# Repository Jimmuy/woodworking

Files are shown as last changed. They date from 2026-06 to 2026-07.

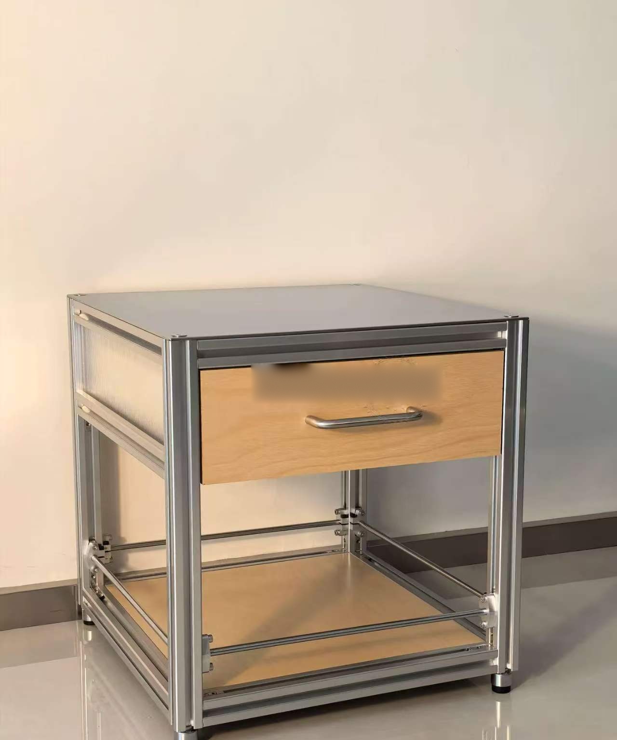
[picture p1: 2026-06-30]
nightstand/Nightstand3.jpg

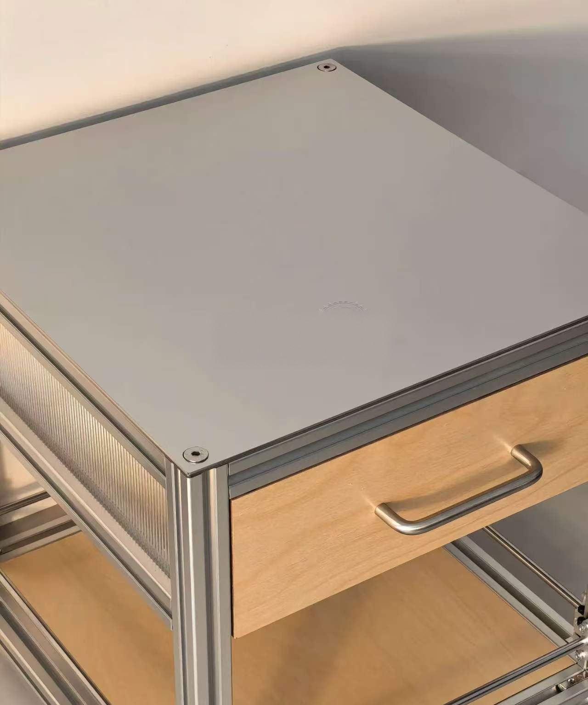
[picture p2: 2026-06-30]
nightstand/Nightstand2.jpg

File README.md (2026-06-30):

# Woodworking

Personal woodworking and small fabrication project archive.

This repository is used to keep project reference photos, design notes, CAD/OpenSCAD models, fabrication checklists, exported review files, and assembly planning documents.

## Projects

### `nightstand/`

Aluminum-profile nightstand / bedside cabinet project.

Contents:

- `床头柜建模.scad` - OpenSCAD parametric machining and assembly model.
- `床头柜加工清单.md` - fabrication dimensions, hardware BOM, original-list comparison, and assembly feasibility review.
- `Nightstand1.jpg` - `Nightstand5.jpg` - redacted reference photos used for visual and construction details.
- `exports/maycad/` - Windows / MayCAD review exports and notes.
- `exports/maycad/bed_desk_assembly_closed_350.3mf` - preferred complete assembly review file.
- `exports/maycad/bed_desk_assembly_closed_350.stl` - complete assembly STL backup.
- `exports/maycad/bed_desk_drawer_closed_350.stl` - drawer fully-closed state check.
- `exports/maycad/bed_desk_drawer_open_350.stl` - drawer fully-open state check.
- `exports/maycad/bed_desk_top_plate_3mm.stl` - top metal plate check.
- `exports/maycad/README.md` - export-file usage notes.

Current nightstand design baseline:

- Overall size: 400 x 400 x 420 mm.
- Frame: 2020 aluminum extrusion.
- Top plate: 400 x 400 x 3 mm, M5 countersunk holes.
- Drawer slides: 350 mm detachable-inner-rail three-section slides.
- Drawer box: 326 mm wide x 350 mm deep x 112 mm high.

## Conventions

- Keep one project per top-level folder.
- Put reusable models, cut lists, reference photos, and export files under that project folder.
- Redact personal IDs, account names, or watermarks from reference photos before committing.
- Treat generated exports as review/check files; fabrication dimensions should be verified against the source model and project BOM.

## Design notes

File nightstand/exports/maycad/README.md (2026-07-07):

# Windows / MayCAD 检查文件说明

## 优先打开

- `bed_desk_assembly_closed_350.3mf`：完整床头柜，默认抽屉完全关闭。
- `bed_desk_assembly_closed_350.stl`：完整床头柜 STL 备份。
- `bed_desk_assembly_open_350.3mf`：完整床头柜，抽屉按350mm额定行程完全打开。
- `bed_desk_assembly_open_350.stl`：抽屉完全打开总装 STL 备份。
- `bed_desk_exploded_350.3mf`：整柜主要零件和抽屉五面板爆炸图。
- `bed_desk_exploded_350.stl`：爆炸图 STL 备份。
- `bed_desk_exploded_350.scad`：爆炸图独立 OpenSCAD 源文件，直接打开即可看到爆炸图。

## 抽屉检查

- `bed_desk_drawer_closed_350.stl`：抽屉完全关闭检查。
- `bed_desk_drawer_open_350.stl`：抽屉按 350mm 全拉出滑轨完全打开检查，只包含框架、固定轨和抽屉运动件。

## 顶板检查

- `bed_desk_top_plate_3mm.stl`：3mm 顶部金属板、M5 沉头孔、R1.5 外角和 C0.35 轻微破边。

## 当前关键尺寸

- 外形：400 x 400 x 420mm。
- 顶板：400 x 400 x 3mm。
- 2020 立柱：387mm x 4。
- 2020 横梁：360mm x 12。
- 抽屉滑轨：350mm 可拆内轨三节滑轨。
- 抽屉盒：332mm 宽 x 350mm 深 x 112mm 高。
- 抽屉盒结构：左右侧板 + 内前板 + 背板 + 底板，装饰前脸最后可调固定。
- 上层长虹板/亚克力：左右侧板 368 x 148 x 4mm，后侧板 352 x 148 x 4mm，按入槽尺寸和滑轨避让尺寸下料。
- 滑轨隐藏承载条：400 x 30 x 3mm x2；固定轨锁在承载条上，承载条前后端锁入2020立柱槽。
- 抽屉完全关闭：前脸外表面与前侧铝型材外表面平齐。
- 抽屉关闭后后方余量：约 12mm。
- 抽屉底板：320 x 338 x 6mm，四边进入6mm槽，槽底距抽屉侧板下边8mm。
- 抽屉底部结构余量：约 14mm。

## 注意

这些导出文件用于 Windows 端检查空间、外观和装配干涉。正式下料仍以 `../../床头柜加工清单.md` 和 `../../床头柜建模.scad` 为准。

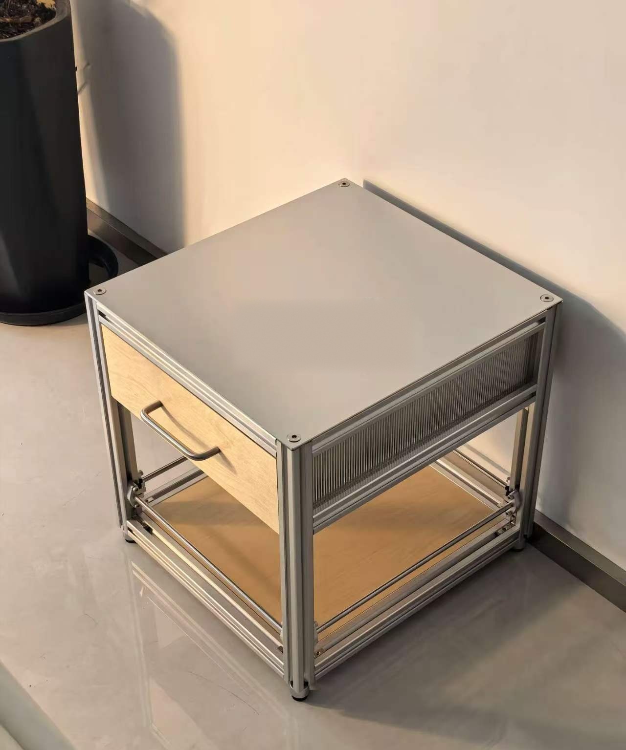
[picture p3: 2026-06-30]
nightstand/Nightstand1.jpg

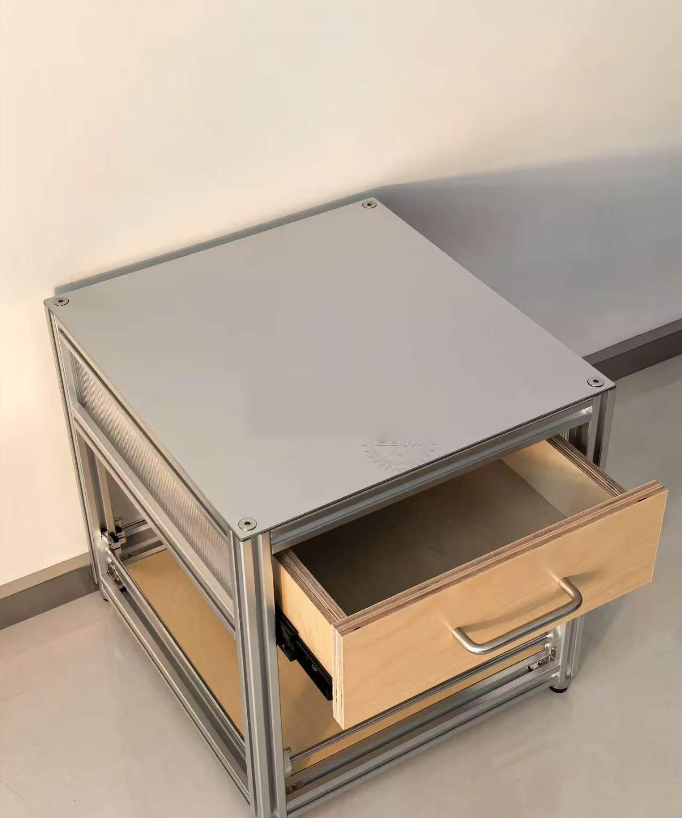
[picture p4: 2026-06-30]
nightstand/Nightstand4.jpg

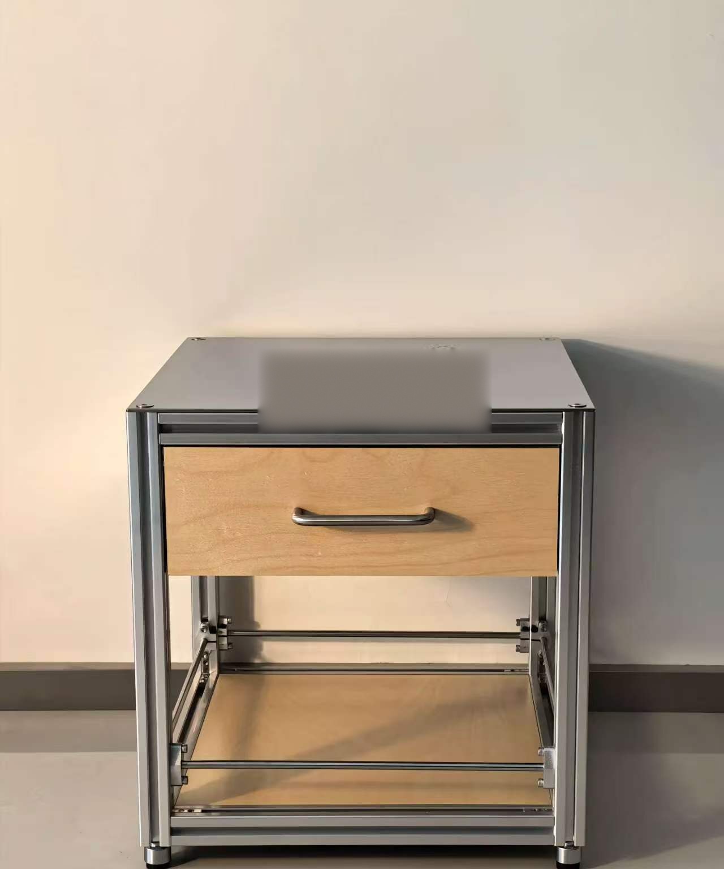
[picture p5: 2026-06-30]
nightstand/Nightstand5.jpg

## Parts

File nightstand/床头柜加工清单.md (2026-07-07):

# 2020铝型材床头柜加工与采购清单

## 设计基准

- 外形尺寸：400mm 宽 × 400mm 深 × 420mm 高。
- 主框架：2020 铝型材，三层框架，四根立柱。
- 上层：木抽屉 + 左右/后侧 4mm 长虹玻璃或亚克力；左右侧板走外侧型材槽位，板边由槽/U型胶条/压片遮住，只露出长虹纹理面。抽屉滑轨不固定在亚克力上，需固定在隐藏金属承载条上。
- 下层：18mm 置物板嵌入底层 2020 内框，板面与铝型材上表面齐平；外侧四面 8mm 不锈钢光轴护栏。
- 模型文件：`床头柜建模.scad`，已补入加工尺寸、孔位、滑轨、抽屉板件和主要五金位置。
- 单独导出零件时可修改 `render_target`，支持 `assembly`、`assembly_open`、`exploded`、`frame`、`top_plate`、`glass_panels`、`shelf`、`guard_rails`、`drawer`、`fixed_slides`、`drawer_install`、`drawer_closed`、`drawer_open`、`feet`。
- 独立爆炸图源文件：`bed_desk_exploded_350.scad`，默认打开即为整柜主要零件和抽屉五面板爆炸图。
- 型材接口按隐藏盲连/内置连接件处理，外侧不要布置外露黑色螺丝。

## 型材下料与加工

| 项目 | 规格 | 数量 | 加工要求 |
| --- | --- | ---: | --- |
| 2020铝型材立柱 | 387mm | 4根 | 顶端按顶部沉头螺丝攻 M5 或采用卖家配套端面连接件；底部调节脚若用M6，需确认型材中心孔可攻M6或加转换脚座。 |
| 2020铝型材横梁 | 360mm | 12根 | 三层框架，每层4根；使用隐藏盲连/内置连接件，外侧不要外露螺丝头。 |
| 型材总长 | 5868mm | 约5.9m | 考虑锯缝和备料，建议采购 6.2m 到 6.5m。 |
| 盲连打孔/攻牙 | M6 或按卖家系统 | 1套 | 需要让型材卖家确认“2020盲连/直连”加工方案，避免只买螺丝但无法锁紧。 |

## 板材和面材下料

| 项目 | 尺寸 | 数量 | 说明 |
| --- | --- | ---: | --- |
| 顶部金属板 | 400 × 400 × 3mm | 1块 | 304不锈钢或铝板；四角预留 M5 沉头孔，孔中心距外边约10mm，对应四根立柱中心；沉头直径约10.5mm、深约2.5mm，螺丝装后与板面平齐；外角建议 R1.5-R2，四周只做 C0.3-C0.5 轻微破边。 |
| 底层置物板 | 356 × 356 × 18mm | 1块 | 嵌入底层2020内框，顶面与底层横梁上表面齐平；下方由槽内托片承重，不要只靠压片夹住。 |
| 左右侧长虹板/亚克力 | 368 × 148 × 4mm | 2块 | 上层抽屉区侧面，按 360×140 开口、单边约5mm入槽和单边约1mm余量计算；嵌入型材槽/U型胶条后正面基本看不到板边。 |
| 后侧长虹板/亚克力 | 352 × 148 × 4mm | 1块 | 后侧板不穿到左右滑轨承载条区域；由上下槽/U型胶条和侧向限位片固定，避免与后端滑轨承载条干涉。 |
| 抽屉前脸 | 356 × 134 × 18mm | 1块 | 拉手孔距按96mm建模；实际按所购拉手复核。 |
| 抽屉侧板 | 350 × 112 × 12mm | 2块 | 12mm夹板或多层板；深度匹配350mm全拉出滑轨。 |
| 抽屉内前板 | 308 × 112 × 12mm | 1块 | 抽屉盒结构前板；预留长圆孔/过孔，装饰前脸最后从内侧微调后锁紧。 |
| 抽屉背板 | 308 × 112 × 12mm | 1块 | 适配332mm外宽抽屉盒。 |
| 抽屉底板 | 320 × 338 × 6mm | 1块 | 四边进入抽屉侧板/内前板/背板的6mm槽内；槽宽建议6.2mm，槽深6mm，槽底距板件下边8mm。 |
| 滑轨隐藏承载条 | 400 × 30 × 3mm | 2根 | 左右各一根，一体式金属扁条；承载条移到侧面型材槽位内侧，不与抽屉前脸、后侧板、侧面长虹板干涉。两端各2个M5过孔，中段攻M4孔固定滑轨。 |

## 完整五金采购清单

| 类别 | 规格/建议 | 数量 | 用途 |
| --- | --- | ---: | --- |
| 不锈钢光轴/圆管 | 直径8mm，长360mm | 4根 | 下层四面护栏。 |
| 2020槽内式圆杆夹/通用光轴连接件 | 8mm圆杆用，M5/T型滑块固定，抱箍中心相对槽中心需有约14mm偏置 | 8个 | 每根光轴两端固定；优先选能嵌入2020型材槽、带偏置抱箍的通用圆杆夹，不建议用外置SK8座。 |
| 抽屉滑轨 | 350mm三节静音阻尼滑轨，低位侧装/底边侧装，必须可拆内轨/带释放扣 | 1双 | 左右各一根；外固定轨锁在隐藏承载条上，活动内轨先锁到抽屉木盒底边侧面，再从正面推入合轨；不接触亚克力。 |
| 极简一字拉手 | 建议孔距96mm | 1个 | 抽屉前脸。 |
| 型材隐藏连接件/盲连螺丝 | 2020用隐藏盲连件，或按卖家系统 | 24套 | 12根横梁两端连接；外侧不露黑色螺丝头。 |
| 顶板银色沉头螺丝 | M5×8-10 不锈钢沉头内六角/梅花 | 4个 | 固定顶部金属板，装入预留沉头孔后与板面基本齐平。 |
| 槽内滑块螺母 | 2020-M5标准滑块 | 建议50个 | 圆杆夹、滑轨、底板托片、玻璃压条/限位片等；若圆杆夹自带滑块可相应减少。 |
| M5短螺丝 | M5×8 / M5×10 / M5×12 混合，承载条位置优先低头/薄头 | 建议60个 | 搭配槽内滑块，固定各类附件和滑轨承载条；滑轨背后不要使用过厚螺丝头。 |
| 底部调节脚 | M6调节脚，脚杯直径约25-30mm | 4个 | 四根立柱底部找平。 |
| 底板槽内承托片 | 2020槽用L型/托板式，托面约30-40mm | 至少4个，建议6-8个 | 嵌入底层型材槽，从下方承接木板重量，四角/四边布置。 |
| 底板防上浮压片/卡条 | 2020槽用，适配18mm板或按实际板厚 | 4个左右 | 负责限位和防止木板上浮，不作为主要承重件。 |
| 玻璃/亚克力U型胶条 | 4mm板用，建议3.5-4m | 1套 | 三块上层面板四周理论总长约3.06m，考虑切损和转角余量不建议只买3m。 |
| 玻璃压条/限位片 | 2020槽用小压片 | 12个左右 | 每块板四边限位，防止晃动。 |
| 承载条到型材固定件 | M5×8/10低头螺丝 + 2020 T型滑块 | 8套 | 每根承载条前后各2套；过孔直径5.5mm，锁入前后立柱内侧槽。 |
| 滑轨到承载条螺丝 | M4×8低头/盘头螺丝 | 8个，建议买12个 | 每侧固定轨4个；承载条攻M4牙，底孔直径3.3mm。若只用3mm铝条，建议改4-5mm条或加M4拉铆螺母。 |
| 滑轨到抽屉木盒螺丝 | M4×10或滑轨自带木螺丝 | 8个，建议买12个 | 每侧活动内轨4个；锁在抽屉侧板外侧低位，木板预钻2.0-2.5mm导孔。 |
| 抽屉盒连接木螺丝 | M3.5×25或M4×25，需预钻孔 | 8个，建议买12个 | 左右侧板从外侧锁内前板/背板，每个角2个，配木工胶。 |
| 抽屉底板入槽固定 | 木工胶 + 6.2mm槽 | 1套 | 底板四边入槽承托，不建议把6mm底板作为主要吃螺丝件；需要防松可在背板下沿加2颗M3×10限位螺丝。 |
| 抽屉前脸可调固定件 | M4×16/20 + 大垫片，或抽屉前脸调节连接件 | 4套 | 前脸最后安装，用长孔/大垫片微调上下左右缝，保证关闭后与铝型材平齐。 |
| 拉手配套螺丝 | M4，长度适配18mm前脸 | 2个 | 拉手通常自带，但要确认螺丝长度能锁紧。 |
| 木工胶 | 白乳胶/木工胶 | 1支 | 抽屉盒板件连接补强。 |
| 防松件 | 螺纹胶/弹垫/平垫 | 1套 | 振动位置建议使用。 |

## 与原清单对比

| 原清单项目 | 原数量 | 结论 | 还需要补充/修正 |
| --- | ---: | --- | --- |
| 不锈钢光轴/圆管 8mm×360mm | 4根 | 足够 | 无。 |
| 光轴卡槽固定座 | 8个 | 数量够，规格需调整 | 建议改为 2020槽内式8mm圆杆夹/通用光轴连接件，能配合T型滑块嵌入型材槽；不要选外置SK8座。 |
| 抽屉滑轨 300mm | 1双 | 不建议继续用300mm | 400mm深柜体净安装深度约360mm，300mm滑轨能装，但完全关闭后抽屉后方会留下约60mm空隙，储物深度偏浪费。建议改350mm可拆内轨三节滑轨。 |
| 极简一字拉手 | 1个 | 足够 | 需确认孔距；模型按96mm孔距。 |
| 型材连接螺丝 M6/M5×25 | 24个 | 方案需调整 | 参考图接口处不应外露螺丝；建议改为隐藏盲连/内置连接件，数量按12根横梁两端共24套。 |
| 槽内滑块螺母 | 约30个 | 偏少 | 建议增至50个，并配 M5×8/10/12 螺丝约50个。 |
| 底部调节脚 | 4个 | 足够 | 可用M6调节脚，但必须让型材卖家确认底端中心孔可攻M6；若型材统一只能攻M5，则改用M5调节脚或转换脚座。 |

## 原清单缺少的关键项目

| 缺少项目 | 建议数量 | 为什么需要 |
| --- | ---: | --- |
| 2020铝型材立柱 387mm | 4根 | 主框架竖向支撑；长度已按3mm顶板重新计算。 |
| 2020铝型材横梁 360mm | 12根 | 上/中/下三层框架。 |
| 顶部金属板 | 1块 | 形成床头柜台面。 |
| 顶板沉头孔加工和银色沉头螺丝 | 4套 | 固定顶板到四根立柱；螺丝装后应与不锈钢板面基本齐平。 |
| 顶板外轮廓倒角/圆角加工 | 1项 | 顶板外角按2020铝型材外角做 R1.5-R2；四周只做 C0.3-C0.5 轻微破边，不要做过大倒角，否则会露出下方型材角。 |
| 底层置物板 | 1块 | 下层储物面。 |
| 长虹玻璃/亚克力板 | 3块 | 左右/后侧上层围挡；板边需要被型材槽、U型胶条或压片遮住。 |
| 4mm U型胶条和玻璃压片 | 1套 | 固定并防震，不然板件会晃。 |
| 抽屉木板拆料 | 1套 | 原清单只有滑轨和拉手，没有抽屉本体。 |
| 抽屉内前板 | 1块 | 大前脸不能直接作为抽屉盒结构件；需要内前板承受盒体连接，并给装饰前脸预留微调空间。 |
| 抽屉盒连接木螺丝/底板入槽加工 | 1套 | 抽屉盒四角用8颗结构螺丝+木工胶；底板靠四边槽承托，槽宽/槽深必须加工准确。 |
| 抽屉前脸可调固定件 | 4套 | 最后调节抽屉前脸，使完全关闭时与前侧铝型材外表面平齐。 |
| 拉手配套螺丝 | 2个 | 需按18mm前脸确认长度。 |
| 滑轨隐藏承载条 | 400×30×3mm 2根 | 解决滑轨不能打在亚克力上的问题；承载条移到侧面型材槽位内侧，同时避开抽屉前脸、后侧板和侧面长虹板。 |
| 底板槽内承托片 | 至少4个，建议6-8个 | 让底板扣入底层型材内框后有可靠承重支撑，并与型材上表面齐平。 |
| 底板防上浮压片/卡条 | 4个左右 | 防止木板搬动时上浮或滑动，不能替代底部托片承重。 |
| M5短螺丝套装 | 约60个 | 原清单只有滑块螺母，没有足够配套螺丝；新增滑轨承载条后建议增加余量。 |
| 型材加工服务 | 1套 | 包含切割、端面攻牙、盲连孔位，决定能否顺利装配。 |

## 加工前复核点

1. 顶板孔中心按模型是距外边约10mm，适配2020立柱中心孔；下单前让金属板加工方和型材方同时确认。当前模型按 M5 沉头孔：通孔约5.5mm，沉头直径约10.5mm，沉头深约2.5mm，建议使用3mm金属板。
2. 顶板沉头螺丝建议用银色不锈钢件，拧紧后与不锈钢面板基本齐平；如果改 M6，必须同步改通孔、沉头直径、顶板厚度和立柱攻牙规格。型材顶端攻牙规格、底部调节脚螺纹规格必须由同一家型材卖家确认，不能默认M5/M6通用。
3. 顶板外轮廓不要按大 R4 或大倒角处理；建议按实际2020铝型材外角做 R1.5-R2，四周只做 C0.3-C0.5 轻微破边。这样顶板外轮廓能覆盖立柱外角，不会从上方看到下方铝型材角。
4. 如果卖家不支持2020隐藏盲连/内置连接件，改用角码会破坏参考图这种无外露螺丝效果，螺丝和滑块数量也要重新计算。
5. 长虹玻璃/亚克力不能按开口净尺寸下料。左右侧板按 368×148×4mm，后侧板按 352×148×4mm；后侧板主动避开滑轨承载条端部，不再强行做满宽。若采购的2020型材槽深、U型胶条厚度不同，必须按实物重新复核后再下单。
6. 抽屉滑轨实际高度、厚度、孔位差异较大；当前模型按350mm全拉出滑轨计算，关闭时抽屉前脸外表面与前侧铝型材外表面平齐，抽屉后方保留约12mm安全间隙。买到具体滑轨后，应把 `slide_h`、`slide_thk`、`slide_len` 回填到 `床头柜建模.scad`，并保持低位贴近抽屉盒底边。滑轨必须可拆内轨，否则侧板装好后很难完成装配和维护。
7. 滑轨不要安装在亚克力/长虹板上。推荐装配顺序是：先半锁2020框架并预放T型滑块；固定左右隐藏承载条并试装滑轨；确认抽屉合轨顺畅后，把长虹板/亚克力带U型胶条滑入槽内，再最终锁紧框架和压片；抽屉盒在柜体外组装并锁活动内轨，最后从正面推入合轨并调缝。
8. 滑轨隐藏承载条推荐使用一体式 400×30×3mm 金属扁条 ×2。前一次问题来自承载条位置偏内，会和抽屉前脸/侧板区域抢空间；当前模型已把承载条移到侧面型材槽位内侧，静态上与抽屉前脸、后侧板、侧面长虹板均有间隙。
9. 当前模型按 12mm滑轨 + 每侧2mm装配/调节余量计算，抽屉盒外宽为332mm。若实际滑轨厚度变化，抽屉盒外宽应按 `360 - 2 × (滑轨厚度 + 每侧装配余量)` 重新计算；每侧装配余量不建议小于1.5mm。承载条位于侧面型材内侧槽位，不再占用抽屉盒净宽。
10. 如果坚持使用原清单的300mm滑轨，抽屉盒深度应改回300mm，完全关闭后抽屉后方会留约60mm空隙；这不是装不上的问题，而是储物深度利用不足。
11. 抽屉前脸不要和抽屉盒一次性死锁；抽屉盒应包含12mm内前板，装饰前脸用4点可调固定件或长孔+大垫片锁在内前板上，整柜试装后再调平、调缝、锁紧。
12. 长虹玻璃建议倒角或磨边；亚克力更好加工，但耐刮性弱于玻璃。侧面板不要外凸安装，板边应藏进型材框或U型胶条。
13. 底层置物板不要放在型材上方；应下沉嵌入底层2020内框，顶面和底层横梁上表面齐平。底板下方至少四处使用槽内式承托片承重，压片/卡条只负责防上浮和定位。
14. 如果底板承重要放书、设备或较重物品，建议把底板槽内承托片从4个增加到6-8个，前后边各2-3个，左右边按需要补强。
15. 光轴固定件建议采购“2020槽内式8mm圆杆夹/通用光轴连接件”，通常由圆杆夹体 + M5螺丝 + T型滑块组成，能直接嵌入型材槽；抱箍中心相对槽中心需要约14mm偏置，否则圆杆位置会顶住立柱或出现悬空。
16. 抽屉底板采用四边入槽，底板尺寸为320×338×6mm；左右侧板、内前板、背板都需开6.2mm宽、6mm深的底板槽，槽底距板件下边8mm。不开槽会导致底板固定方式和当前模型不一致。
17. 所有板件建议保留0.5-1mm加工误差余量，先试装框架，再锁紧面板和抽屉。

## 抽屉与滑轨下单复核

| 项目 | 当前确认值 | 加工/装配要求 |
| --- | --- | --- |
| 滑轨规格 | 350mm三节全拉出，低位侧装/底边侧装，可拆内轨 | 关闭时抽屉前脸外表面与前侧铝型材外表面齐平；全开按350mm额定行程校核。必须能拆内轨，否则侧板装好后不可维护。 |
| 固定轨安装位置 | 左右隐藏承载条内侧，中心约在抽屉底边上方19.5mm | 滑轨不碰亚克力；承载条先锁到型材，再从抽屉口方向上固定轨。 |
| 活动内轨安装位置 | 抽屉左右侧板外侧低位，滑轨底边距抽屉侧板下边约2mm | 在柜体外先把活动内轨锁到抽屉盒，再从正面推入合轨。 |
| 承载条固定 | 每根承载条前后各2个M5过孔 | 孔径5.5mm，配M5×8/10低头螺丝+2020 T型滑块，共8套。 |
| 固定轨到承载条 | 每侧4颗M4×8，共8颗 | 承载条攻M4，底孔3.3mm；孔位按实际滑轨长圆孔复核，模型示意为y向约 -120、-45、45、120mm。 |
| 活动内轨到抽屉侧板 | 每侧4颗M4×10或滑轨配套木螺丝，共8颗 | 木板预钻2.0-2.5mm导孔，螺丝不要穿透12mm侧板内表面。 |
| 抽屉盒五面板 | 侧板350×112×12mm×2；内前板308×112×12mm×1；背板308×112×12mm×1；底板320×338×6mm×1 | 抽屉盒外宽332mm、深350mm、高112mm；底板四边入槽6mm。 |
| 抽屉盒结构螺丝 | M3.5×25或M4×25，共8颗 | 四个角每角2颗，从左右侧板外侧锁入内前板/背板，配木工胶。 |
| 装饰前脸固定 | M4×16/20 + 大垫片，共4套 | 内前板做长孔/过孔，最后调缝后锁紧；拉手另外2颗M4按拉手配套长度。 |

## 爆炸图对照复核

爆炸图中的主要可加工/采购单元与清单一致：4根立柱、12根横梁、1块顶板、3块长虹板/亚克力、1块底层置物板、4处底板托片、4根光轴、8个光轴连接件、2根滑轨承载条、1副滑轨、抽屉五面板、1块装饰前脸和1个拉手。隐藏盲连件、T型滑块、玻璃压片、胶条、木工胶和防松件属于小五金/耗材，爆炸图不逐个拆开显示，但清单已按装配需要列入。

## 开孔与孔位复核

下表坐标以零件自身为基准，除特别说明外，孔位从零件中心线对称计算；正式打孔前仍需把实际购买滑轨、拉手、圆杆夹和型材槽宽实物复核一遍。

| 零件/孔位 | 孔径/孔型 | 数量 | 孔中心位置 |
| --- | --- | ---: | --- |
| 顶部金属板固定孔 | M5通孔 Ø5.5；90度沉头 Ø10.5，深约2.5mm | 4 | 板面坐标 X/Y = ±190mm，即距四边各10mm，对应4根2020立柱中心孔。 |
| 滑轨隐藏承载条到型材 | M5过孔 Ø5.5 | 8 | 每根400×30×3mm承载条4孔：长度方向距两端各10mm；高度方向距下边7mm和23mm。配M5×8/10低头螺丝+2020 T型滑块。 |
| 固定轨到滑轨承载条 | M4攻牙，底孔 Ø3.3；若不用攻牙则改 Ø4.5 过孔+铆螺母/背母 | 8 | 每根承载条4孔，模型参考为距前端约75、150、240、315mm，高度方向距下边15mm。实际以所购滑轨长圆孔为准，建议先装承载条和滑轨试位后再钻。 |
| 活动内轨到抽屉侧板 | 按滑轨配套木螺丝预钻 Ø2.0-2.5，或M4木螺丝导孔 | 8 | 每侧4孔；模型参考为距抽屉侧板前端约57、132、222、297mm，高度方向距侧板下边约19.5mm。实际以所购滑轨孔位为准。 |
| 抽屉前脸拉手孔 | M4通孔 Ø4.5 | 2 | 孔距96mm；在356×134mm前脸上，孔中心距左边约130mm和226mm，距上下边各67mm。 |
| 抽屉内前板到装饰前脸调节孔 | 竖向长孔 5×14mm，配M4×16/20和大垫片 | 4 | 在308×112mm内前板上，孔中心距左边约42mm和266mm；距下边约22mm和90mm。 |
| 抽屉盒侧板连接孔 | M3.5/M4木螺丝预钻；侧板通孔可按 Ø3.5-4.2，端面导孔按 Ø2.0-2.5 | 8 | 左右侧板从外侧锁内前板/背板；前后方向孔中心距侧板前/后端约6mm，高度方向距侧板下边18mm和94mm。 |
| 抽屉底板槽 | 6.2mm宽槽，槽深6mm | 4条槽 | 左右侧板、内前板、背板都开槽；槽底距板件下边8mm，适配320×338×6mm底板四边入槽。 |
| 底板托片/玻璃压片/光轴夹 | 通常用M5过孔 Ø5.5或购买件自带孔 | 按所购件 | 爆炸图只表达位置关系；这三类优先买2020槽内标准件，孔位按实物，不建议自行先打死孔。 |

## 本次静态与运动校核结果

本次按模型关键零件包围盒做了静态和抽屉0-350mm行程运动校核。滑轨固定轨/活动轨的套叠、抽屉底板四边入槽属于预期装配接触，不按干涉处理；其余最小单元未发现静态干涉和运动干涉。

| 校核项 | 结果 |
| --- | --- |
| 侧面长虹板到滑轨承载条 | X向净间隙约5mm。 |
| 侧面长虹板到固定滑轨 | X向净间隙约8.5mm。 |
| 抽屉前脸到滑轨承载条 | X向净间隙约2mm。 |
| 抽屉前脸到固定滑轨 | 关闭状态Y向净间隙约2mm。 |
| 后侧长虹板到滑轨承载条 | X向净间隙约4mm。 |
| 抽屉侧板到活动滑轨 | X向装配间隙约0.5mm，需按实际滑轨厚度复核。 |
| 抽屉完全关闭 | 前脸外表面Y=-200mm，与前侧铝型材外表面平齐；抽屉后方余量约12mm。 |
| 抽屉完全打开 | 抽屉盒背板相对固定滑轨/前框仍有约2mm间隙。活动轨与固定轨在额定350mm全开位置为滑轨内部止挡接触，属于标准全拉出状态；若购买超行程滑轨，需把实际行程回填模型再复核。 |
| 抽屉底部 | 抽屉盒底边到下方开口横梁约14mm，滑轨低位安装后仍可装配。 |

## 装配可行性复核

| 模块 | 可行性结论 | 关键检查 |
| --- | --- | --- |
| 铝型材框架 | 可装配 | 12根横梁使用隐藏盲连/内置连接件，外侧不露螺丝；下单时必须把盲连孔、端面攻牙和切割一起给型材卖家确认。 |
| 顶部金属板 | 可装配，需确认攻牙 | 3mm板可做M5沉头并保持平齐；四角孔位在立柱中心，顶端攻牙规格必须和M5沉头螺丝一致。 |
| 抽屉滑轨 | 可装配 | 选350mm可拆内轨三节滑轨；固定轨锁在400mm隐藏承载条上，承载条前后端锁入2020立柱槽；活动内轨在柜体外锁到抽屉盒，再从正面推入合轨。 |
| 抽屉盒 | 可装配 | 外宽332mm，深350mm，高112mm；增加12mm内前板，底板为320×338mm四边入槽；每侧保留2mm装配/调节余量；装饰前脸用4点可调固定件，最后调缝并锁紧。 |
| 侧面长虹板/亚克力 | 可装配 | 左右下料按368×148mm并走外侧槽位，后侧下料按352×148mm避开滑轨承载条端部；三块板均不承受滑轨载荷，不打滑轨孔。 |
| 底层置物板 | 可装配 | 底板嵌入底层内框，顶面与型材齐平；至少4个槽内承托片承重，压片/卡条只做防上浮和定位。 |
| 下层光轴护栏 | 可装配 | 采购2020槽内式8mm圆杆夹，配M5滑块，抱箍中心需相对槽中心有约14mm偏置；不要买外置SK8座，否则外观和装配空间都会偏离参考图。 |
| 调节脚 | 可装配，需确认螺纹 | M6脚垫稳定性较好，但需要底端攻M6或转换脚座；若型材卖家只能统一M5，则改M5脚垫。 |

## Windows/MayCAD 导出说明

- OpenSCAD 当前可直接导出 `STL`、`3MF`、`AMF`、`OFF`、`CSG` 等格式；本项目优先导出 `STL` 和 `3MF` 给 Windows 端确认。
- 本机没有 FreeCAD/CadQuery，因此不直接输出 STEP。若你的 Windows MayCAD 只支持 STEP/IGES，需要在 Windows 端用 FreeCAD、Fusion、SolidWorks 或 MayCAD 支持的转换工具从 STL/3MF 另转，或者提供 MayCAD 的明确导入格式后再重新导出。
- `STL` 是网格模型，适合确认空间、外观、干涉和装配关系；真正下料仍以本清单尺寸和 `床头柜建模.scad` 参数为准。

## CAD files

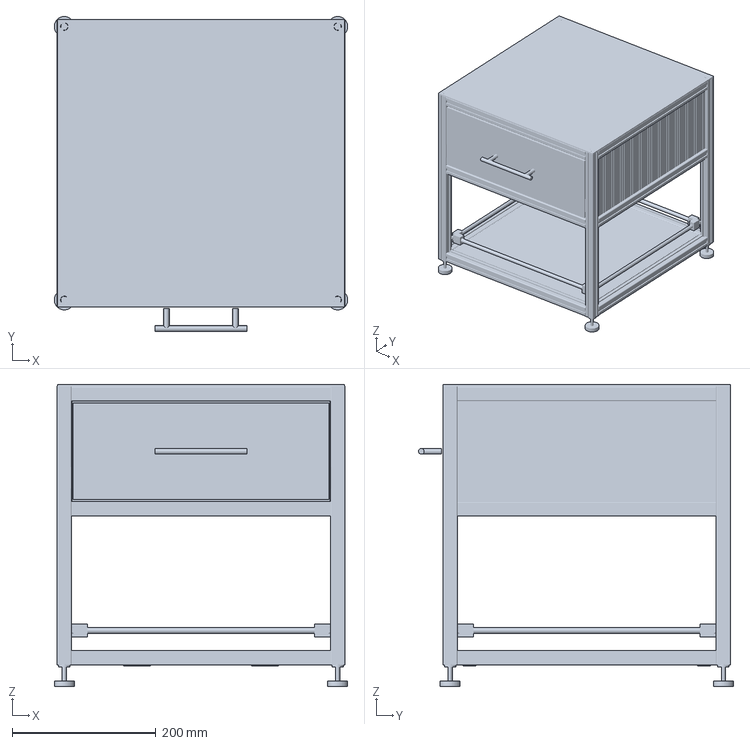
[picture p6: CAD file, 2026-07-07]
nightstand/exports/maycad/bed_desk_assembly_closed_350.3mf
408.0 x 438.0 x 420.0 mm

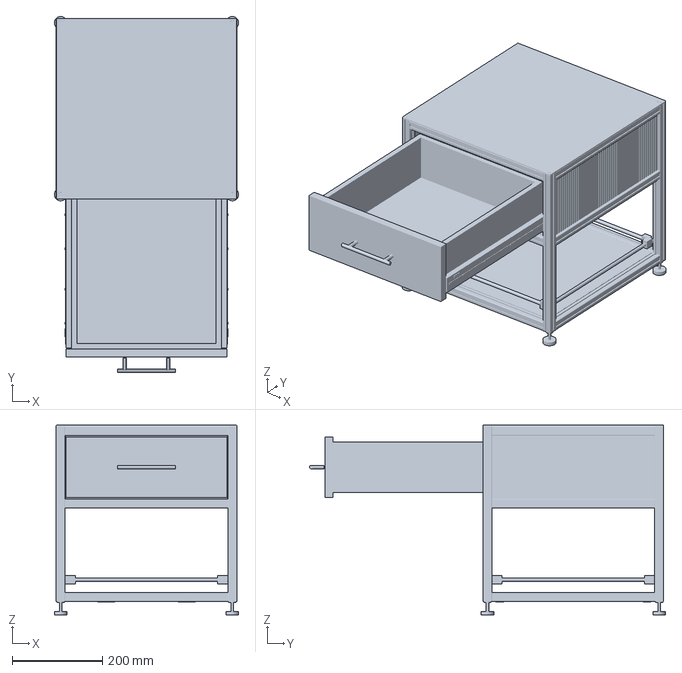
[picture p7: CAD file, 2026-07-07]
nightstand/bed_desk_assembly_open_350.3mf
408.0 x 788.0 x 420.0 mm

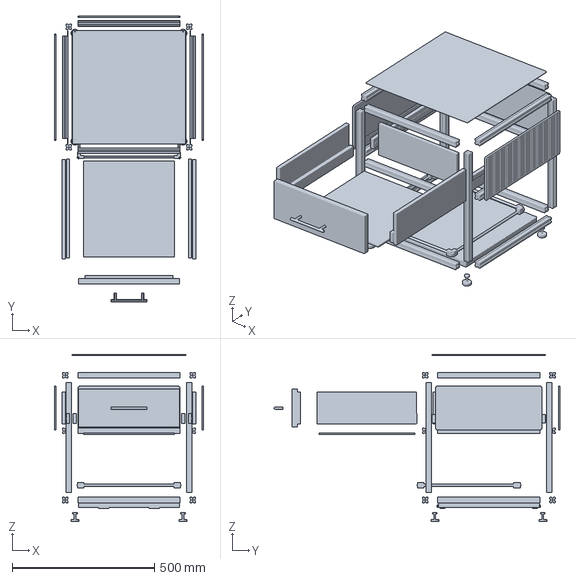
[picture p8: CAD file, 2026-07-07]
nightstand/bed_desk_exploded_350.3mf
525.7 x 1006.4 x 588.0 mm

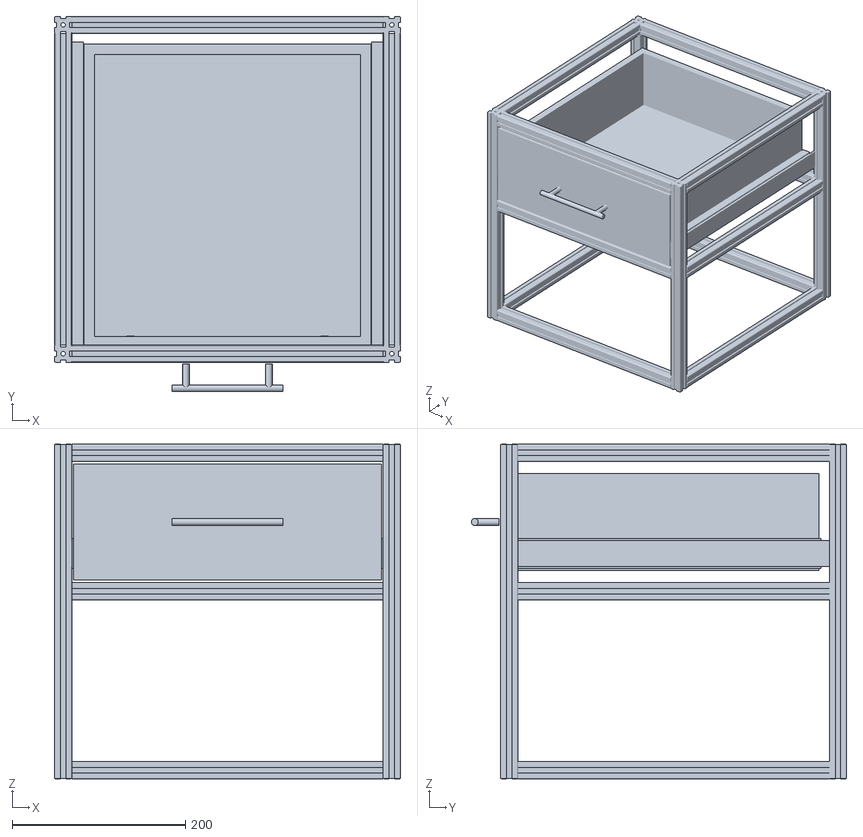
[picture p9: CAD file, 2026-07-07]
nightstand/exports/maycad/bed_desk_drawer_closed_350.stl
400.0 x 434.0 x 387.0

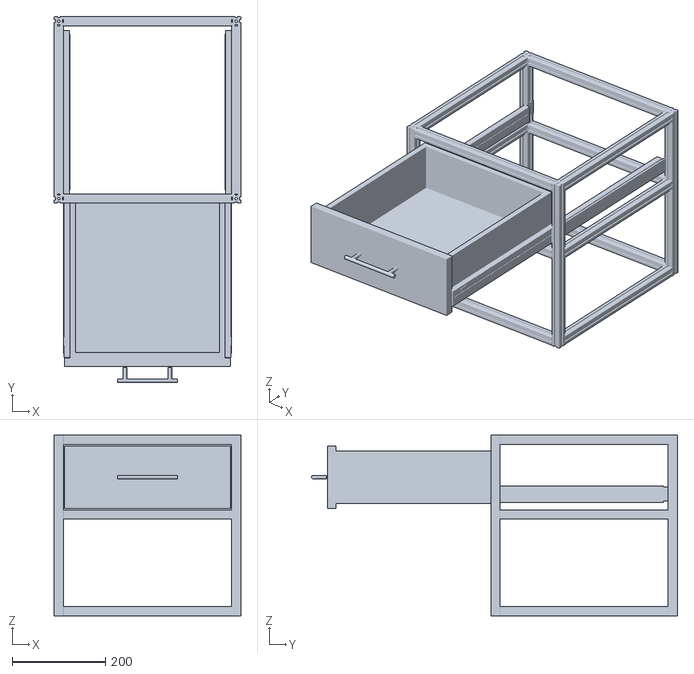
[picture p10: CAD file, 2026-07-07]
nightstand/exports/maycad/bed_desk_drawer_open_350.stl
400.0 x 784.0 x 387.0

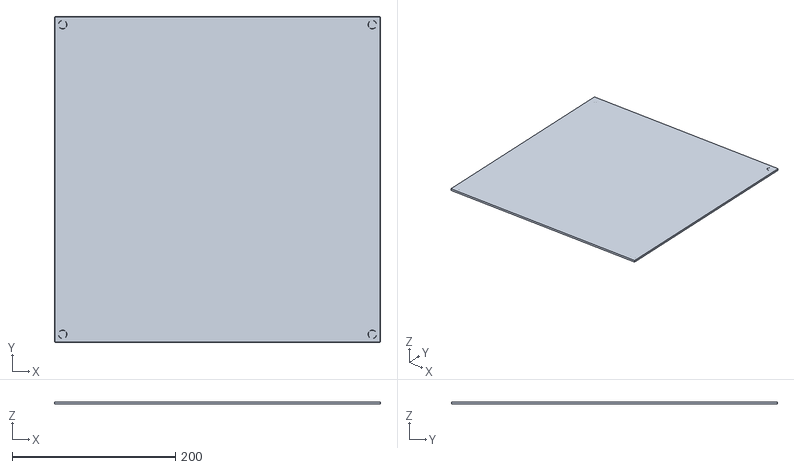
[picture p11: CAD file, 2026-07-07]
nightstand/exports/maycad/bed_desk_top_plate_3mm.stl
400.0 x 400.0 x 3.03

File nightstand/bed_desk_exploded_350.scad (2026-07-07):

// ==============================================================================
// 2020铝型材床头柜 - 加工装配模型
// 单位：mm
//
// 目标：
// 1. 作为加工沟通模型，而不是单纯外观示意；
// 2. 明确型材下料、板件尺寸、孔位、滑轨、光轴座、调节脚和主要五金位置；
// 3. 所有关键尺寸都集中在参数区，方便按实际采购件微调。
//
// 注意：
// display_gap 只用于避免 OpenSCAD 导出 STL 时多个零件共面导致布尔歧义。
// 采购/加工尺寸以 *_cut_len、板件尺寸和本文件 echo 输出为准。
// ==============================================================================

$fn = 48;
eps = 0.02;
display_gap = 0.15;
explode_gap = 70;

// --- 总体尺寸 ---
cabinet_width  = 400;
cabinet_depth  = 400;
cabinet_height = 420;

// --- 型材与板材 ---
profile_size       = 20;   // 2020铝型材
profile_corner_r   = 1.5;  // 2020型材外角小圆角；用于让顶板外角匹配型材视觉
top_plate_thk      = 3;    // 顶部金属板；3mm更适合做M5沉头并保持板面平齐
top_plate_corner_r = profile_corner_r; // 顶板外角与型材外角一致，避免露出下方型材角
top_plate_edge_chamfer = 0.35; // 顶板只做轻微破边，不做过大的四周倒角
shelf_thk          = 18;   // 底层置物板
shelf_support_w    = 38;   // 底板槽内式承托片托面宽度
shelf_support_d    = 18;
shelf_support_thk  = 3;
shelf_support_lug_h= 8;
glass_thk          = 4;    // 长虹玻璃/亚克力
glass_slot_embed   = 5;    // 每边进入2020槽/U型胶条的有效深度
glass_install_clearance = 1; // 每边安装余量，避免板件过紧无法滑入
foot_height        = 30;

// --- 抽屉与滑轨 ---
drawer_front_w     = 356;
drawer_front_h     = 134;
drawer_front_thk   = 18;
drawer_box_h       = 112;
drawer_body_thk    = 12;
drawer_bottom_thk  = 6;
drawer_bottom_groove_depth = 6; // 底板四边进入抽屉盒板槽的深度
drawer_bottom_groove_lift  = 8; // 底板槽底距抽屉侧板下边，给滑轨螺丝和底边留肉
slide_len          = 350;
slide_travel       = slide_len; // 三节全拉出滑轨，按额定长度≈额定行程建模
drawer_box_depth   = slide_len; // 抽屉盒深度匹配滑轨长度，避免320盒体配300滑轨的非标悬伸
slide_h            = 35;
slide_thk          = 12;
slide_carrier_thk  = 3;    // 隐藏式金属承载条，固定在2020槽内，滑轨不打在亚克力上
slide_carrier_h    = 30;
slide_carrier_len  = 400;  // 一体式隐藏承载条；移到侧面型材槽位后不再与抽屉前脸/后板干涉
slide_mount_gap    = 0.5;
drawer_side_working_clearance = 2; // 每侧装配/调节余量；保证抽屉能从正面合轨推入
slide_bottom_clearance = 2; // 参考图为低位侧装，贴近抽屉盒底边
drawer_open_ratio  = 0; // 默认整柜为闭合状态；需要开启预览时改为0.35-1
render_target      = "exploded";
// 可选导出目标：
// "assembly"       整体装配预览
// "frame"          铝型材框架，接口按内置/盲连处理，不显示外露螺丝
// "top_plate"      顶部金属板、倒角外轮廓、预留沉头孔和平齐银色沉头螺丝
// "glass_panels"   三块长虹板/亚克力及嵌条
// "shelf"          底层嵌入式置物板和装配缝
// "guard_rails"    下层四面光轴护栏
// "drawer"         抽屉盒、前脸、拉手和活动滑轨
// "fixed_slides"   隐藏承载条和固定在承载条上的滑轨
// "drawer_install" 抽屉安装预览：框架+固定轨，抽屉带活动内轨从正面推入
// "drawer_closed"  抽屉完全关闭检查：前脸外表面与前侧铝型材外表面平齐
// "drawer_open"    抽屉完全打开检查：按滑轨额定全拉出行程
// "assembly_open"  完整床头柜，抽屉按350mm额定行程完全打开
// "exploded"       整柜主要零件和抽屉五面板爆炸图
// "feet"           四个调节脚

// --- 五金参数 ---
rod_d              = 8;
rail_support_w     = 18;
rail_support_h     = 18;
rail_support_d     = 12;
rod_support_inset  = 13.5;
handle_spacing     = 96;
handle_width       = 128;
handle_rod_d       = 8;
handle_standoff    = 28;
drawer_front_fix_x = 112;  // 抽屉前脸内侧4点可调固定，先调缝再锁紧
drawer_front_fix_z = 34;
drawer_front_fix_head_d = 9;
drawer_front_slot_w = 5;
drawer_front_slot_h = 14;
top_hole_d         = 5.5;  // 当前按M5沉头螺钉预留；若改M6需同步孔径
top_csk_d          = 10.5;
top_csk_depth      = 2.5;  // M5 90度沉头按约2.5mm深度建模，适配3mm板
top_socket_d       = 3.2;
glass_rib_step     = 7;
glass_rib_w        = 0.55;
glass_rib_depth    = 0.7;

// --- 派生尺寸 ---
post_x = cabinet_width/2 - profile_size/2;
post_y = cabinet_depth/2 - profile_size/2;

top_plate_z0     = cabinet_height - top_plate_thk;
frame_bottom_z   = foot_height;
pillar_cut_len   = top_plate_z0 - frame_bottom_z;
beam_x_cut_len   = cabinet_width - 2*profile_size;
beam_y_cut_len   = cabinet_depth - 2*profile_size;
drawer_box_w     = beam_x_cut_len - 2*(slide_thk + drawer_side_working_clearance);

top_beam_z       = top_plate_z0 - profile_size/2;
drawer_bay_h     = 140;
middle_beam_z    = top_beam_z - profile_size - drawer_bay_h;
bottom_beam_z    = frame_bottom_z + profile_size/2;

upper_open_top_z    = top_beam_z - profile_size/2;
upper_open_bottom_z = middle_beam_z + profile_size/2;
upper_open_h        = upper_open_top_z - upper_open_bottom_z;

glass_side_panel_len = beam_y_cut_len + 2*(glass_slot_embed - glass_install_clearance);
glass_back_panel_len = beam_x_cut_len - 8;
glass_panel_h     = upper_open_h + 2*(glass_slot_embed - glass_install_clearance);
glass_z           = (upper_open_top_z + upper_open_bottom_z) / 2;
glass_side_x      = post_x;
glass_back_y      = post_y - profile_size/2 - glass_thk/2 - 0.5;

shelf_size        = beam_x_cut_len - 4;
shelf_top_z       = bottom_beam_z + profile_size/2 - display_gap;
shelf_z           = shelf_top_z - shelf_thk/2;
shelf_bottom_z    = shelf_z - shelf_thk/2;
guard_rail_z      = shelf_top_z + 28;
guard_side_x      = post_x - profile_size/2 - rod_d/2 - display_gap;
guard_front_y     = -(post_y - profile_size/2 - rod_d/2 - display_gap);
guard_back_y      =  (post_y - profile_size/2 - rod_d/2 - display_gap);

drawer_z                = glass_z;
front_profile_outer_y   = -cabinet_depth/2;
drawer_rear_inner_limit_y = post_y - profile_size/2;
drawer_front_flush_inset= 0; // 0=抽屉前脸外表面与前侧铝型材外表面平齐
drawer_front_y_closed   = front_profile_outer_y + drawer_front_flush_inset + drawer_front_thk/2;
drawer_box_y_closed     = drawer_front_y_closed + drawer_front_thk/2 + drawer_box_depth/2;
drawer_inner_front_y     = drawer_box_y_closed - drawer_box_depth/2 + drawer_body_thk/2;
drawer_open_y           = -slide_travel * drawer_open_ratio;
drawer_full_open_y      = -slide_travel;
slide_center_y_closed   = -cabinet_depth/2 + profile_size + slide_len/2;
slide_carrier_x         = post_x - profile_size/2 + slide_carrier_thk/2;
slide_carrier_center_y  = 0;
slide_fixed_x           = slide_carrier_x - slide_carrier_thk/2 - slide_mount_gap - slide_thk/2;
drawer_box_bottom_z     = drawer_z - drawer_box_h/2;
slide_moving_y_closed   = slide_center_y_closed;
slide_z                 = drawer_box_bottom_z + slide_h/2 + slide_bottom_clearance;
drawer_front_outer_y_closed = drawer_front_y_closed - drawer_front_thk/2;
drawer_back_y_closed    = drawer_box_y_closed + drawer_box_depth/2;
drawer_back_clearance_closed = drawer_rear_inner_limit_y - drawer_back_y_closed;
drawer_bottom_clearance = drawer_box_bottom_z - upper_open_bottom_z;
drawer_inner_panel_w    = drawer_box_w - 2*drawer_body_thk;
drawer_bottom_w         = drawer_inner_panel_w + 2*drawer_bottom_groove_depth;
drawer_bottom_depth     = drawer_box_depth - 2*drawer_body_thk + 2*drawer_bottom_groove_depth;
drawer_bottom_z         = drawer_box_bottom_z + drawer_bottom_groove_lift + drawer_bottom_thk/2;

echo(str("CUT 2020 vertical posts: ", pillar_cut_len, "mm x 4"));
echo(str("CUT 2020 horizontal beams X/Y: ", beam_x_cut_len, "mm x 12"));
echo(str("CUT stainless/aluminum top plate: ", cabinet_width, " x ", cabinet_depth, " x ", top_plate_thk, "mm, R", top_plate_corner_r, " corners, C", top_plate_edge_chamfer, " light edge break, M5 countersunk holes at +/-", post_x, "mm"));
echo(str("CUT bottom shelf: ", shelf_size, " x ", shelf_size, " x ", shelf_thk, "mm x 1, inset flush with lower 2020 frame top"));
echo(str("CUT side glass/acrylic: ", glass_side_panel_len, " x ", glass_panel_h, " x ", glass_thk, "mm x 2"));
echo(str("CUT back glass/acrylic: ", glass_back_panel_len, " x ", glass_panel_h, " x ", glass_thk, "mm x 1"));
echo(str("CUT drawer front: ", drawer_front_w, " x ", drawer_front_h, " x ", drawer_front_thk, "mm x 1"));
echo(str("CUT drawer sides: ", drawer_box_depth, " x ", drawer_box_h, " x ", drawer_body_thk, "mm x 2"));
echo(str("CUT drawer inner front: ", drawer_inner_panel_w, " x ", drawer_box_h, " x ", drawer_body_thk, "mm x 1, slotted holes for adjustable decorative front"));
echo(str("CUT drawer back: ", drawer_inner_panel_w, " x ", drawer_box_h, " x ", drawer_body_thk, "mm x 1"));
echo(str("CUT drawer bottom: ", drawer_bottom_w, " x ", drawer_bottom_depth, " x ", drawer_bottom_thk, "mm x 1, four edges enter ", drawer_bottom_groove_depth, "mm grooves"));
echo(str("CUT slide carrier bars: ", slide_carrier_len, " x ", slide_carrier_h, " x ", slide_carrier_thk, "mm x 2, M5 end holes and M4 tapped slide holes"));
echo(str("CHECK drawer closed: front face Y=", drawer_front_outer_y_closed, "mm, front profile outer Y=", front_profile_outer_y, "mm"));
echo(str("CHECK drawer rear clearance closed: ", drawer_back_clearance_closed, "mm"));
echo(str("CHECK drawer bottom clearance above opening lower profile: ", drawer_bottom_clearance, "mm"));
echo(str("CHECK drawer full open travel: ", slide_travel, "mm, drawer box depth: ", drawer_box_depth, "mm"));

// --- 颜色 ---
color_profile  = [0.72, 0.72, 0.68];
color_slot     = [0.18, 0.18, 0.18];
color_wood     = [0.78, 0.56, 0.32];
color_wood_dark= [0.52, 0.30, 0.14];
color_metal    = [0.78, 0.78, 0.76];
color_screw_silver = [0.86, 0.86, 0.82];
color_socket   = [0.06, 0.06, 0.06];
color_hardware = [0.02, 0.02, 0.02];
color_glass    = [0.78, 0.80, 0.76, 0.28];
color_glass_rib= [0.95, 0.95, 0.90, 0.38];

// ==============================================================================
// 基础几何
// ==============================================================================
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

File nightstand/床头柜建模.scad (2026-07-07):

// ==============================================================================
// 2020铝型材床头柜 - 加工装配模型
// 单位：mm
//
// 目标：
// 1. 作为加工沟通模型，而不是单纯外观示意；
// 2. 明确型材下料、板件尺寸、孔位、滑轨、光轴座、调节脚和主要五金位置；
// 3. 所有关键尺寸都集中在参数区，方便按实际采购件微调。
//
// 注意：
// display_gap 只用于避免 OpenSCAD 导出 STL 时多个零件共面导致布尔歧义。
// 采购/加工尺寸以 *_cut_len、板件尺寸和本文件 echo 输出为准。
// ==============================================================================

$fn = 48;
eps = 0.02;
display_gap = 0.15;
explode_gap = 70;

// --- 总体尺寸 ---
cabinet_width  = 400;
cabinet_depth  = 400;
cabinet_height = 420;

// --- 型材与板材 ---
profile_size       = 20;   // 2020铝型材
profile_corner_r   = 1.5;  // 2020型材外角小圆角；用于让顶板外角匹配型材视觉
top_plate_thk      = 3;    // 顶部金属板；3mm更适合做M5沉头并保持板面平齐
top_plate_corner_r = profile_corner_r; // 顶板外角与型材外角一致，避免露出下方型材角
top_plate_edge_chamfer = 0.35; // 顶板只做轻微破边，不做过大的四周倒角
shelf_thk          = 18;   // 底层置物板
shelf_support_w    = 38;   // 底板槽内式承托片托面宽度
shelf_support_d    = 18;
shelf_support_thk  = 3;
shelf_support_lug_h= 8;
glass_thk          = 4;    // 长虹玻璃/亚克力
glass_slot_embed   = 5;    // 每边进入2020槽/U型胶条的有效深度
glass_install_clearance = 1; // 每边安装余量，避免板件过紧无法滑入
foot_height        = 30;

// --- 抽屉与滑轨 ---
drawer_front_w     = 356;
drawer_front_h     = 134;
drawer_front_thk   = 18;
drawer_box_h       = 112;
drawer_body_thk    = 12;
drawer_bottom_thk  = 6;
drawer_bottom_groove_depth = 6; // 底板四边进入抽屉盒板槽的深度
drawer_bottom_groove_lift  = 8; // 底板槽底距抽屉侧板下边，给滑轨螺丝和底边留肉
slide_len          = 350;
slide_travel       = slide_len; // 三节全拉出滑轨，按额定长度≈额定行程建模
drawer_box_depth   = slide_len; // 抽屉盒深度匹配滑轨长度，避免320盒体配300滑轨的非标悬伸
slide_h            = 35;
slide_thk          = 12;
slide_carrier_thk  = 3;    // 隐藏式金属承载条，固定在2020槽内，滑轨不打在亚克力上
slide_carrier_h    = 30;
slide_carrier_len  = 400;  // 一体式隐藏承载条；移到侧面型材槽位后不再与抽屉前脸/后板干涉
slide_mount_gap    = 0.5;
drawer_side_working_clearance = 2; // 每侧装配/调节余量；保证抽屉能从正面合轨推入
slide_bottom_clearance = 2; // 参考图为低位侧装，贴近抽屉盒底边
drawer_open_ratio  = 0; // 默认整柜为闭合状态；需要开启预览时改为0.35-1
render_target      = "assembly";
// 可选导出目标：
// "assembly"       整体装配预览
// "frame"          铝型材框架，接口按内置/盲连处理，不显示外露螺丝
// "top_plate"      顶部金属板、倒角外轮廓、预留沉头孔和平齐银色沉头螺丝
// "glass_panels"   三块长虹板/亚克力及嵌条
// "shelf"          底层嵌入式置物板和装配缝
// "guard_rails"    下层四面光轴护栏
// "drawer"         抽屉盒、前脸、拉手和活动滑轨
// "fixed_slides"   隐藏承载条和固定在承载条上的滑轨
// "drawer_install" 抽屉安装预览：框架+固定轨，抽屉带活动内轨从正面推入
// "drawer_closed"  抽屉完全关闭检查：前脸外表面与前侧铝型材外表面平齐
// "drawer_open"    抽屉完全打开检查：按滑轨额定全拉出行程
// "assembly_open"  完整床头柜，抽屉按350mm额定行程完全打开
// "exploded"       整柜主要零件和抽屉五面板爆炸图
// "feet"           四个调节脚

// --- 五金参数 ---
rod_d              = 8;
rail_support_w     = 18;
rail_support_h     = 18;
rail_support_d     = 12;
rod_support_inset  = 13.5;
handle_spacing     = 96;
handle_width       = 128;
handle_rod_d       = 8;
handle_standoff    = 28;
drawer_front_fix_x = 112;  // 抽屉前脸内侧4点可调固定，先调缝再锁紧
drawer_front_fix_z = 34;
drawer_front_fix_head_d = 9;
drawer_front_slot_w = 5;
drawer_front_slot_h = 14;
top_hole_d         = 5.5;  // 当前按M5沉头螺钉预留；若改M6需同步孔径
top_csk_d          = 10.5;
top_csk_depth      = 2.5;  // M5 90度沉头按约2.5mm深度建模，适配3mm板
top_socket_d       = 3.2;
glass_rib_step     = 7;
glass_rib_w        = 0.55;
glass_rib_depth    = 0.7;

// --- 派生尺寸 ---
post_x = cabinet_width/2 - profile_size/2;
post_y = cabinet_depth/2 - profile_size/2;

top_plate_z0     = cabinet_height - top_plate_thk;
frame_bottom_z   = foot_height;
pillar_cut_len   = top_plate_z0 - frame_bottom_z;
beam_x_cut_len   = cabinet_width - 2*profile_size;
beam_y_cut_len   = cabinet_depth - 2*profile_size;
drawer_box_w     = beam_x_cut_len - 2*(slide_thk + drawer_side_working_clearance);

top_beam_z       = top_plate_z0 - profile_size/2;
drawer_bay_h     = 140;
middle_beam_z    = top_beam_z - profile_size - drawer_bay_h;
bottom_beam_z    = frame_bottom_z + profile_size/2;

upper_open_top_z    = top_beam_z - profile_size/2;
upper_open_bottom_z = middle_beam_z + profile_size/2;
upper_open_h        = upper_open_top_z - upper_open_bottom_z;

glass_side_panel_len = beam_y_cut_len + 2*(glass_slot_embed - glass_install_clearance);
glass_back_panel_len = beam_x_cut_len - 8;
glass_panel_h     = upper_open_h + 2*(glass_slot_embed - glass_install_clearance);
glass_z           = (upper_open_top_z + upper_open_bottom_z) / 2;
glass_side_x      = post_x;
glass_back_y      = post_y - profile_size/2 - glass_thk/2 - 0.5;

shelf_size        = beam_x_cut_len - 4;
shelf_top_z       = bottom_beam_z + profile_size/2 - display_gap;
shelf_z           = shelf_top_z - shelf_thk/2;
shelf_bottom_z    = shelf_z - shelf_thk/2;
guard_rail_z      = shelf_top_z + 28;
guard_side_x      = post_x - profile_size/2 - rod_d/2 - display_gap;
guard_front_y     = -(post_y - profile_size/2 - rod_d/2 - display_gap);
guard_back_y      =  (post_y - profile_size/2 - rod_d/2 - display_gap);

drawer_z                = glass_z;
front_profile_outer_y   = -cabinet_depth/2;
drawer_rear_inner_limit_y = post_y - profile_size/2;
drawer_front_flush_inset= 0; // 0=抽屉前脸外表面与前侧铝型材外表面平齐
drawer_front_y_closed   = front_profile_outer_y + drawer_front_flush_inset + drawer_front_thk/2;
drawer_box_y_closed     = drawer_front_y_closed + drawer_front_thk/2 + drawer_box_depth/2;
drawer_inner_front_y     = drawer_box_y_closed - drawer_box_depth/2 + drawer_body_thk/2;
drawer_open_y           = -slide_travel * drawer_open_ratio;
drawer_full_open_y      = -slide_travel;
slide_center_y_closed   = -cabinet_depth/2 + profile_size + slide_len/2;
slide_carrier_x         = post_x - profile_size/2 + slide_carrier_thk/2;
slide_carrier_center_y  = 0;
slide_fixed_x           = slide_carrier_x - slide_carrier_thk/2 - slide_mount_gap - slide_thk/2;
drawer_box_bottom_z     = drawer_z - drawer_box_h/2;
slide_moving_y_closed   = slide_center_y_closed;
slide_z                 = drawer_box_bottom_z + slide_h/2 + slide_bottom_clearance;
drawer_front_outer_y_closed = drawer_front_y_closed - drawer_front_thk/2;
drawer_back_y_closed    = drawer_box_y_closed + drawer_box_depth/2;
drawer_back_clearance_closed = drawer_rear_inner_limit_y - drawer_back_y_closed;
drawer_bottom_clearance = drawer_box_bottom_z - upper_open_bottom_z;
drawer_inner_panel_w    = drawer_box_w - 2*drawer_body_thk;
drawer_bottom_w         = drawer_inner_panel_w + 2*drawer_bottom_groove_depth;
drawer_bottom_depth     = drawer_box_depth - 2*drawer_body_thk + 2*drawer_bottom_groove_depth;
drawer_bottom_z         = drawer_box_bottom_z + drawer_bottom_groove_lift + drawer_bottom_thk/2;

echo(str("CUT 2020 vertical posts: ", pillar_cut_len, "mm x 4"));
echo(str("CUT 2020 horizontal beams X/Y: ", beam_x_cut_len, "mm x 12"));
echo(str("CUT stainless/aluminum top plate: ", cabinet_width, " x ", cabinet_depth, " x ", top_plate_thk, "mm, R", top_plate_corner_r, " corners, C", top_plate_edge_chamfer, " light edge break, M5 countersunk holes at +/-", post_x, "mm"));
echo(str("CUT bottom shelf: ", shelf_size, " x ", shelf_size, " x ", shelf_thk, "mm x 1, inset flush with lower 2020 frame top"));
echo(str("CUT side glass/acrylic: ", glass_side_panel_len, " x ", glass_panel_h, " x ", glass_thk, "mm x 2"));
echo(str("CUT back glass/acrylic: ", glass_back_panel_len, " x ", glass_panel_h, " x ", glass_thk, "mm x 1"));
echo(str("CUT drawer front: ", drawer_front_w, " x ", drawer_front_h, " x ", drawer_front_thk, "mm x 1"));
echo(str("CUT drawer sides: ", drawer_box_depth, " x ", drawer_box_h, " x ", drawer_body_thk, "mm x 2"));
echo(str("CUT drawer inner front: ", drawer_inner_panel_w, " x ", drawer_box_h, " x ", drawer_body_thk, "mm x 1, slotted holes for adjustable decorative front"));
echo(str("CUT drawer back: ", drawer_inner_panel_w, " x ", drawer_box_h, " x ", drawer_body_thk, "mm x 1"));
echo(str("CUT drawer bottom: ", drawer_bottom_w, " x ", drawer_bottom_depth, " x ", drawer_bottom_thk, "mm x 1, four edges enter ", drawer_bottom_groove_depth, "mm grooves"));
echo(str("CUT slide carrier bars: ", slide_carrier_len, " x ", slide_carrier_h, " x ", slide_carrier_thk, "mm x 2, M5 end holes and M4 tapped slide holes"));
echo(str("CHECK drawer closed: front face Y=", drawer_front_outer_y_closed, "mm, front profile outer Y=", front_profile_outer_y, "mm"));
echo(str("CHECK drawer rear clearance closed: ", drawer_back_clearance_closed, "mm"));
echo(str("CHECK drawer bottom clearance above opening lower profile: ", drawer_bottom_clearance, "mm"));
echo(str("CHECK drawer full open travel: ", slide_travel, "mm, drawer box depth: ", drawer_box_depth, "mm"));

// --- 颜色 ---
color_profile  = [0.72, 0.72, 0.68];
color_slot     = [0.18, 0.18, 0.18];
color_wood     = [0.78, 0.56, 0.32];
color_wood_dark= [0.52, 0.30, 0.14];
color_metal    = [0.78, 0.78, 0.76];
color_screw_silver = [0.86, 0.86, 0.82];
color_socket   = [0.06, 0.06, 0.06];
color_hardware = [0.02, 0.02, 0.02];
color_glass    = [0.78, 0.80, 0.76, 0.28];
color_glass_rib= [0.95, 0.95, 0.90, 0.38];

// ==============================================================================
// 基础几何
// ==============================================================================
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

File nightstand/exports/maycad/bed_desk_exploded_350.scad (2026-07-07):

// ==============================================================================
// 2020铝型材床头柜 - 加工装配模型
// 单位：mm
//
// 目标：
// 1. 作为加工沟通模型，而不是单纯外观示意；
// 2. 明确型材下料、板件尺寸、孔位、滑轨、光轴座、调节脚和主要五金位置；
// 3. 所有关键尺寸都集中在参数区，方便按实际采购件微调。
//
// 注意：
// display_gap 只用于避免 OpenSCAD 导出 STL 时多个零件共面导致布尔歧义。
// 采购/加工尺寸以 *_cut_len、板件尺寸和本文件 echo 输出为准。
// ==============================================================================

$fn = 48;
eps = 0.02;
display_gap = 0.15;
explode_gap = 70;

// --- 总体尺寸 ---
cabinet_width  = 400;
cabinet_depth  = 400;
cabinet_height = 420;

// --- 型材与板材 ---
profile_size       = 20;   // 2020铝型材
profile_corner_r   = 1.5;  // 2020型材外角小圆角；用于让顶板外角匹配型材视觉
top_plate_thk      = 3;    // 顶部金属板；3mm更适合做M5沉头并保持板面平齐
top_plate_corner_r = profile_corner_r; // 顶板外角与型材外角一致，避免露出下方型材角
top_plate_edge_chamfer = 0.35; // 顶板只做轻微破边，不做过大的四周倒角
shelf_thk          = 18;   // 底层置物板
shelf_support_w    = 38;   // 底板槽内式承托片托面宽度
shelf_support_d    = 18;
shelf_support_thk  = 3;
shelf_support_lug_h= 8;
glass_thk          = 4;    // 长虹玻璃/亚克力
glass_slot_embed   = 5;    // 每边进入2020槽/U型胶条的有效深度
glass_install_clearance = 1; // 每边安装余量，避免板件过紧无法滑入
foot_height        = 30;

// --- 抽屉与滑轨 ---
drawer_front_w     = 356;
drawer_front_h     = 134;
drawer_front_thk   = 18;
drawer_box_h       = 112;
drawer_body_thk    = 12;
drawer_bottom_thk  = 6;
drawer_bottom_groove_depth = 6; // 底板四边进入抽屉盒板槽的深度
drawer_bottom_groove_lift  = 8; // 底板槽底距抽屉侧板下边，给滑轨螺丝和底边留肉
slide_len          = 350;
slide_travel       = slide_len; // 三节全拉出滑轨，按额定长度≈额定行程建模
drawer_box_depth   = slide_len; // 抽屉盒深度匹配滑轨长度，避免320盒体配300滑轨的非标悬伸
slide_h            = 35;
slide_thk          = 12;
slide_carrier_thk  = 3;    // 隐藏式金属承载条，固定在2020槽内，滑轨不打在亚克力上
slide_carrier_h    = 30;
slide_carrier_len  = 400;  // 一体式隐藏承载条；移到侧面型材槽位后不再与抽屉前脸/后板干涉
slide_mount_gap    = 0.5;
drawer_side_working_clearance = 2; // 每侧装配/调节余量；保证抽屉能从正面合轨推入
slide_bottom_clearance = 2; // 参考图为低位侧装，贴近抽屉盒底边
drawer_open_ratio  = 0; // 默认整柜为闭合状态；需要开启预览时改为0.35-1
render_target      = "exploded";
// 可选导出目标：
// "assembly"       整体装配预览
// "frame"          铝型材框架，接口按内置/盲连处理，不显示外露螺丝
// "top_plate"      顶部金属板、倒角外轮廓、预留沉头孔和平齐银色沉头螺丝
// "glass_panels"   三块长虹板/亚克力及嵌条
// "shelf"          底层嵌入式置物板和装配缝
// "guard_rails"    下层四面光轴护栏
// "drawer"         抽屉盒、前脸、拉手和活动滑轨
// "fixed_slides"   隐藏承载条和固定在承载条上的滑轨
// "drawer_install" 抽屉安装预览：框架+固定轨，抽屉带活动内轨从正面推入
// "drawer_closed"  抽屉完全关闭检查：前脸外表面与前侧铝型材外表面平齐
// "drawer_open"    抽屉完全打开检查：按滑轨额定全拉出行程
// "assembly_open"  完整床头柜，抽屉按350mm额定行程完全打开
// "exploded"       整柜主要零件和抽屉五面板爆炸图
// "feet"           四个调节脚

// --- 五金参数 ---
rod_d              = 8;
rail_support_w     = 18;
rail_support_h     = 18;
rail_support_d     = 12;
rod_support_inset  = 13.5;
handle_spacing     = 96;
handle_width       = 128;
handle_rod_d       = 8;
handle_standoff    = 28;
drawer_front_fix_x = 112;  // 抽屉前脸内侧4点可调固定，先调缝再锁紧
drawer_front_fix_z = 34;
drawer_front_fix_head_d = 9;
drawer_front_slot_w = 5;
drawer_front_slot_h = 14;
top_hole_d         = 5.5;  // 当前按M5沉头螺钉预留；若改M6需同步孔径
top_csk_d          = 10.5;
top_csk_depth      = 2.5;  // M5 90度沉头按约2.5mm深度建模，适配3mm板
top_socket_d       = 3.2;
glass_rib_step     = 7;
glass_rib_w        = 0.55;
glass_rib_depth    = 0.7;

// --- 派生尺寸 ---
post_x = cabinet_width/2 - profile_size/2;
post_y = cabinet_depth/2 - profile_size/2;

top_plate_z0     = cabinet_height - top_plate_thk;
frame_bottom_z   = foot_height;
pillar_cut_len   = top_plate_z0 - frame_bottom_z;
beam_x_cut_len   = cabinet_width - 2*profile_size;
beam_y_cut_len   = cabinet_depth - 2*profile_size;
drawer_box_w     = beam_x_cut_len - 2*(slide_thk + drawer_side_working_clearance);

top_beam_z       = top_plate_z0 - profile_size/2;
drawer_bay_h     = 140;
middle_beam_z    = top_beam_z - profile_size - drawer_bay_h;
bottom_beam_z    = frame_bottom_z + profile_size/2;

upper_open_top_z    = top_beam_z - profile_size/2;
upper_open_bottom_z = middle_beam_z + profile_size/2;
upper_open_h        = upper_open_top_z - upper_open_bottom_z;

glass_side_panel_len = beam_y_cut_len + 2*(glass_slot_embed - glass_install_clearance);
glass_back_panel_len = beam_x_cut_len - 8;
glass_panel_h     = upper_open_h + 2*(glass_slot_embed - glass_install_clearance);
glass_z           = (upper_open_top_z + upper_open_bottom_z) / 2;
glass_side_x      = post_x;
glass_back_y      = post_y - profile_size/2 - glass_thk/2 - 0.5;

shelf_size        = beam_x_cut_len - 4;
shelf_top_z       = bottom_beam_z + profile_size/2 - display_gap;
shelf_z           = shelf_top_z - shelf_thk/2;
shelf_bottom_z    = shelf_z - shelf_thk/2;
guard_rail_z      = shelf_top_z + 28;
guard_side_x      = post_x - profile_size/2 - rod_d/2 - display_gap;
guard_front_y     = -(post_y - profile_size/2 - rod_d/2 - display_gap);
guard_back_y      =  (post_y - profile_size/2 - rod_d/2 - display_gap);
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

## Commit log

2026-06-30 Add nightstand model and fabrication docs
    [bed_desk_assembly_closed_350.3mf, bed_desk_drawer_closed_350.stl, bed_desk_drawer_open_350.stl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]
2026-07-01 Refine nightstand assembly purchase specs
    [bed_desk_assembly_closed_350.3mf, bed_desk_drawer_closed_350.stl, bed_desk_drawer_open_350.stl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]
2026-07-07 update ---add new feature
    [bed_desk_assembly_closed_350.3mf, bed_desk_assembly_open_350.3mf, bed_desk_drawer_closed_350.stl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]
